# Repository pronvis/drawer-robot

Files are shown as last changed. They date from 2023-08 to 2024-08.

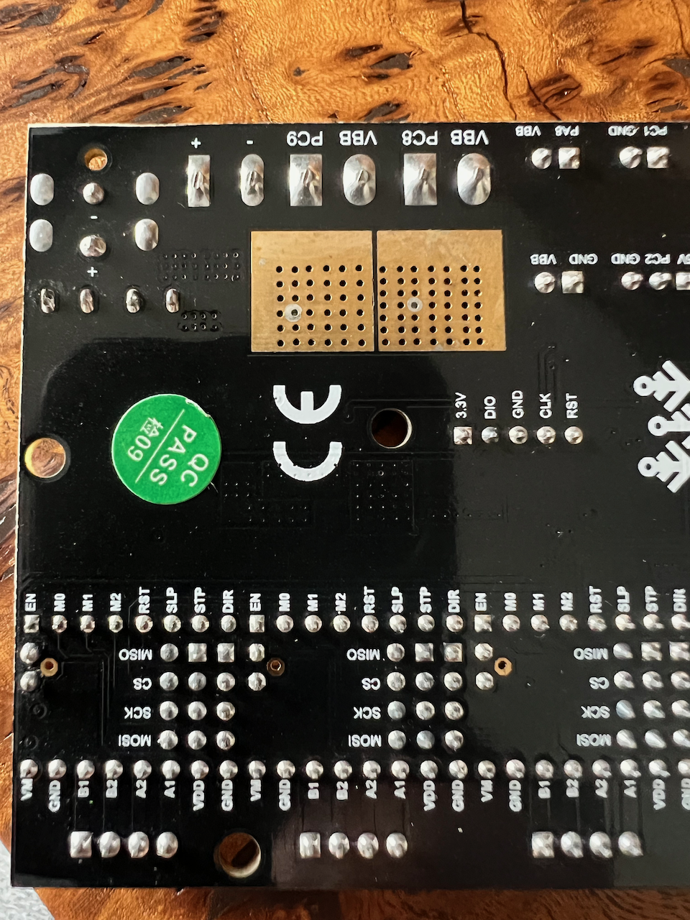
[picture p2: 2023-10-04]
documentation/SKR E3-DIP-V1.1_pins_1.png

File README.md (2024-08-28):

Based on https://github.com/knurling-rs/app-template

## Run
To execute binary file: `cargo xtask run -p {project_name} -b {bin_file_name}`, for example: `cargo xtask run -p experiments -b stepper_configurator`.
Or just `cargo xtask run -b stepper_configurator`, cause `experiments` is the default project for `run` task: `XTASK_RUN_DEFAULT = "experiments"`
To execute main file: `cargo xtask run -p {project_name}`.
To set logging level change env vat `DEFMT_LOG` at `.cargo/config.toml`

### To stop microcontoller
Erase program: `probe-rs erase --chip STM32F103RE`

## Size
To get info about sections size on microcontoller: `cargo xtask size -p {project_name} -b {bin_file_name}`, for example: `cargo xtask size -p experiments -b stepper_configurator`.

## ReadObj
To get info about binary object: `cargo xtask readobj -p {project_name} -b {bin_file_name}`, for example: `cargo xtask readobj -p experiments -b stepper_configurator`.

## Attach
To attach to running microcontroller, example:
1) `probe-rs attach $CARGO_TARGET_DIR/thumbv7m-none-eabi/release/companion --chip STM32F103C8 --probe 0483:3748:C296C294070132124647524B4E --log-format "[{t}][{L}] {s}"`
2) `probe-rs attach $CARGO_TARGET_DIR/thumbv7m-none-eabi/release/motherboard --chip STM32F103RE --probe 0483:3748:15 --log-format "[{t}][{L}] {s}"`

## TMC2209

Good Vref calculator: https://wiki.fysetc.com/TMC2208/#motor-current-setting
For my steppers (1.7A for phase) Vref should be `1.6970562748477143`,
but I set it to 1.9, cause my friend told me that active cooling required above Vref=1.4

## PS3 controller bluetooth connection

To connect PS3 controller to HC-05 you need to set master address. To do that:
- install SixAxisPairTool (for mac get it from [here](https://github.com/user-none/sixaxispairer))
- connect PS3 to PC
- set master address

## Debugging

1. run `openopcd` in one terminal
2. run `arm-none-eabi-gdb -x openocd.gdb -q {path_to_bin_file}` or change `runner` at `crate/{project}/.cargo/config.toml`
For example: `arm-none-eabi-gdb -x openocd.gdb -q ~/rust/rust_build_artifacts/thumbv7m-none-eabi/release/minimal_x`

## Manual Flashing

1. Build ELF file (`cargo build`)
2. `arm-none-eabi-objcopy -O binary $CARGO_TARGET_DIR/thumbv7m-none-eabi/release/{binary_name} {path_to_output}.bin`
3. `st-flash write {path_to_output}.bin 0x08000000`

## HC-05

Use arduino device to configure HC-05. Scetch and connection image is in folder `./hc05_arduino_configurator/`.
With pressed button `reset` connect HC-05 to arduino - diod whould blink once per 2 seconds.

Commands can be found in `./documentation/HC-05_AT_Command_Set.pdf`

One device should be Master. Another one slave.

I set speed to 460800: `AT+UART=460800,0,0`

For slave: 
- `AT+NAME=DrawingRobot_slave`
- `AT+UART=460800,0,0`
- `AT+CMODE=1`
- `AT+ROLE=0`
- get addr, we will need it for master: `AT+ADDR?`

For master: 
- `AT+NAME=DrawingRobot_master`
- `AT+UART=460800,0,0`
- `AT+CMODE=0`
- `AT+BIND={slave_addr}` // replace `:` with `,` in addr string
- `AT+ROLE=1`

For `AT+BIND={slave_addr}` it may require adding zeroes in front each part. For example: `AT+ADDR?` return
`21:13:12622`. To bind that address send this command: `AT+BIND=0021,13,012622`

## Images

Motherboard:


Companion:


companion

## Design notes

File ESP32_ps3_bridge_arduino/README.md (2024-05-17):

## Run
To install firmware you need:
- Arduino IDE
- `PS3 Controller Host` library installed, version 1.1.0
- choose `ESP32-WROOM-DA Module` as a board

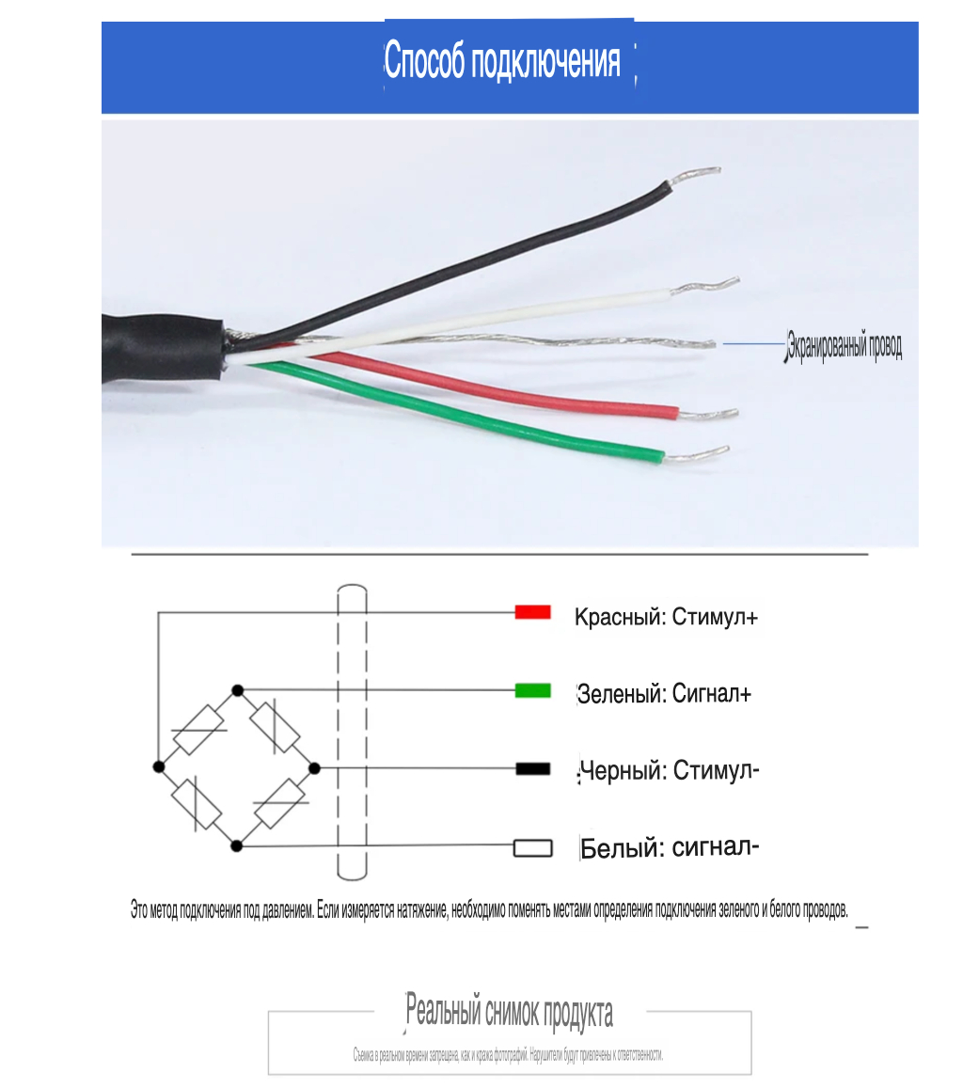
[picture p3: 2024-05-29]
documentation/dymh-106/connection_to_translate.translated.jpg

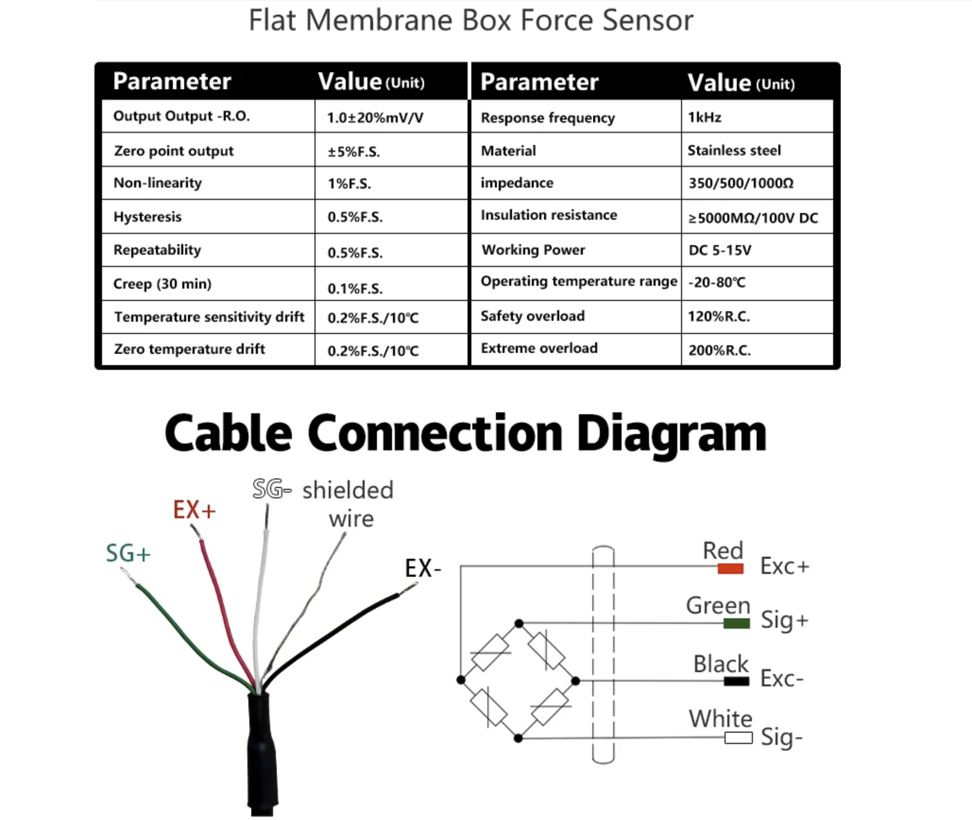
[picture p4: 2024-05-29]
documentation/dymh-106/connection_diagram.png

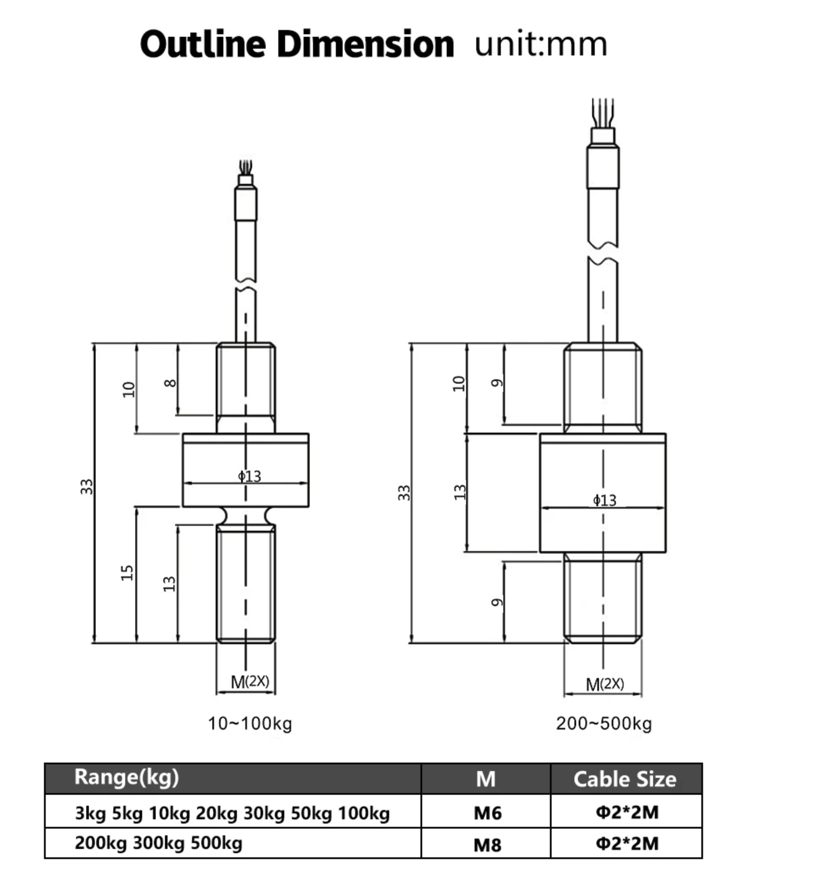
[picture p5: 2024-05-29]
documentation/dymh-106/size.png

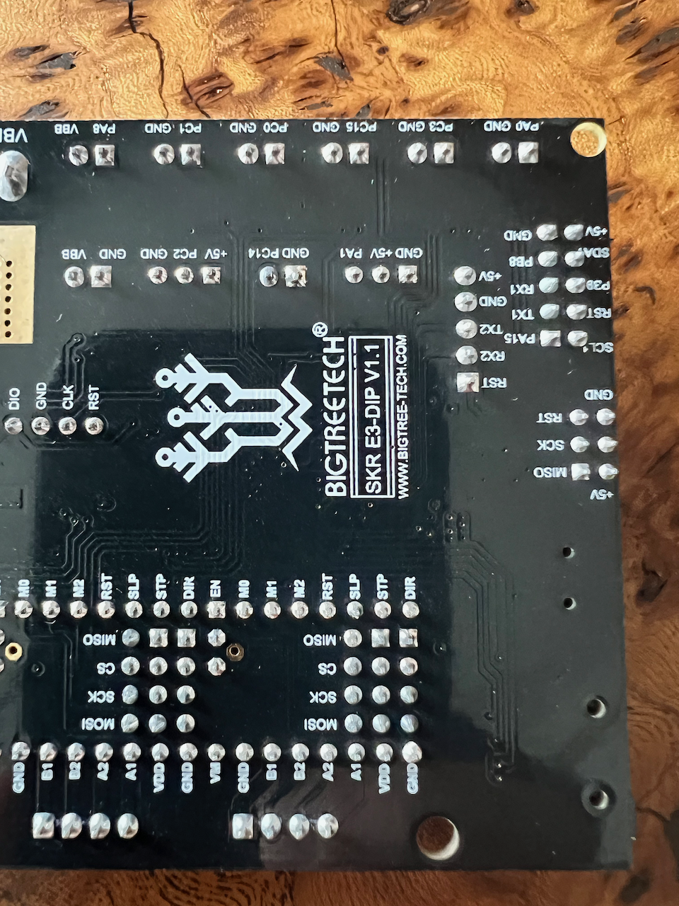
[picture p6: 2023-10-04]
documentation/SKR E3-DIP-V1.1_pins_0.png

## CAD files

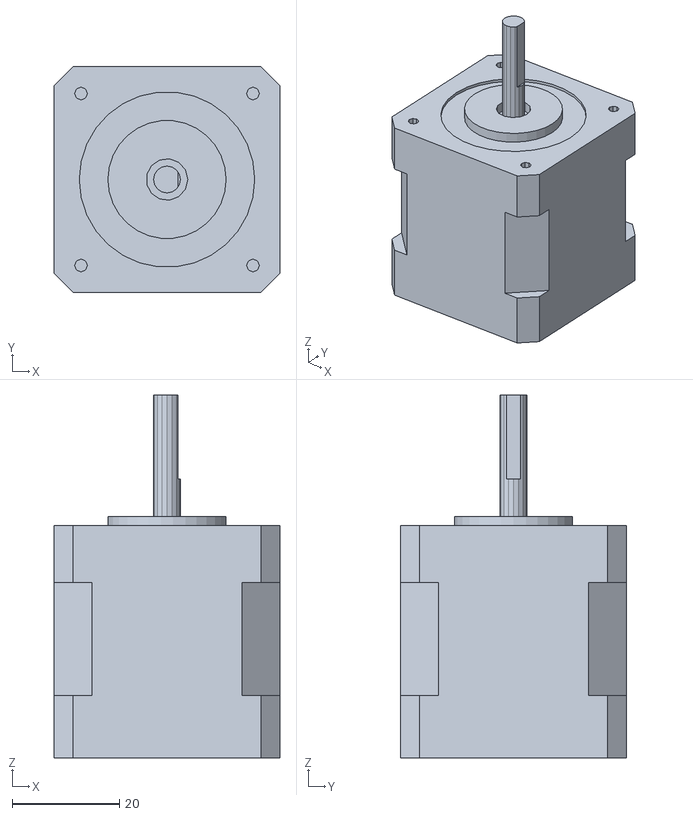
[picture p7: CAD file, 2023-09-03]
open_scad/reduction_gearbox/Nema17.stl
42.0 x 42.0 x 67.5

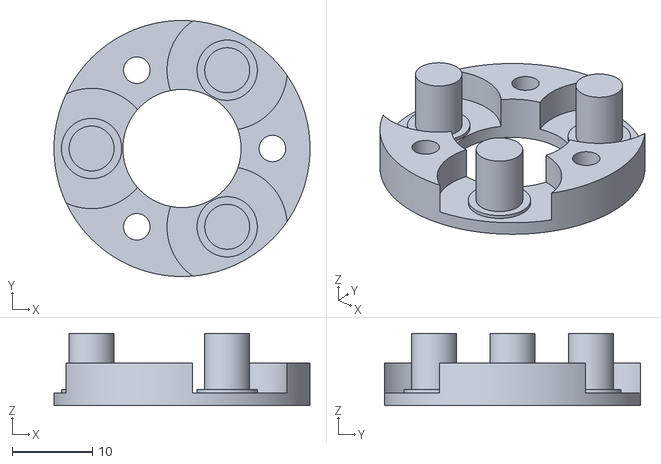
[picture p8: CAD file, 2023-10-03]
open_scad/stl_files/gearbox_carrier_bottom.stl
31.9 x 31.9 x 9.00

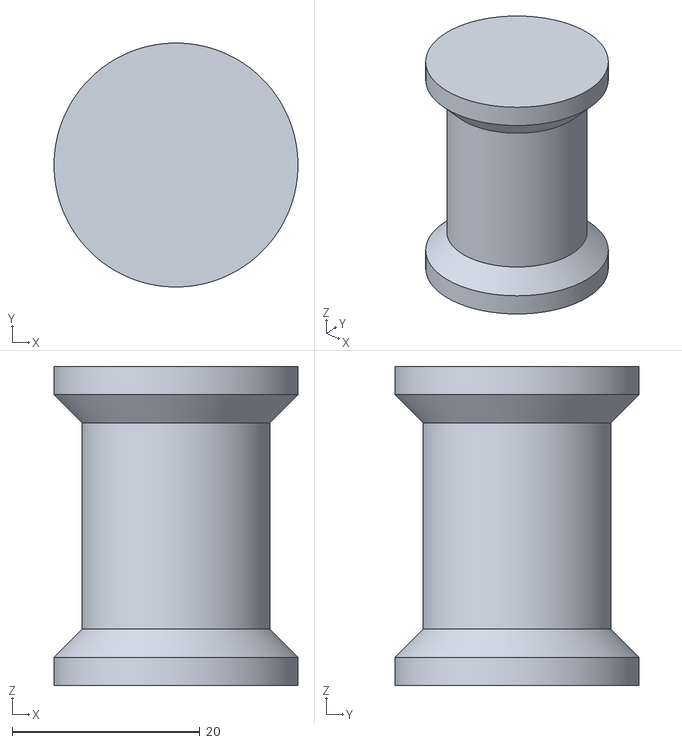
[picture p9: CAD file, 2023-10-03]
open_scad/stl_files/katushka.stl
26.0 x 26.0 x 34.0

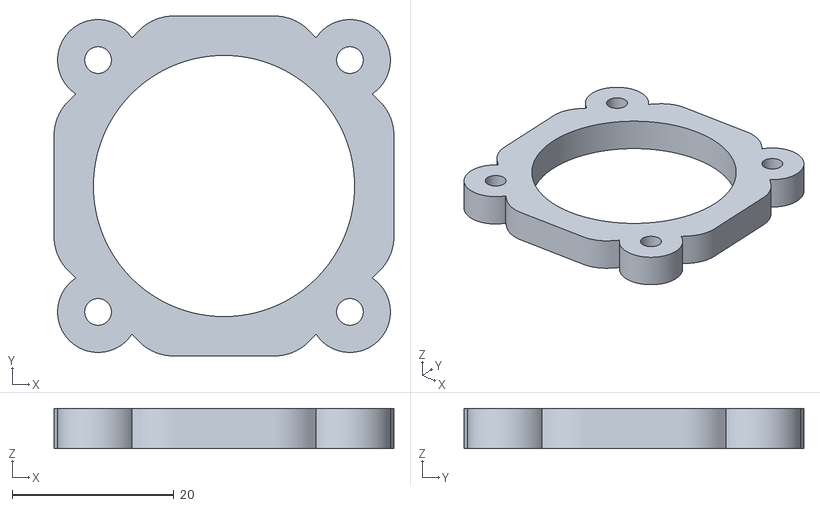
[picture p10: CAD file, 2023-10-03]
open_scad/stl_files/gearbox_fixer.stl
42.0 x 42.0 x 5.00

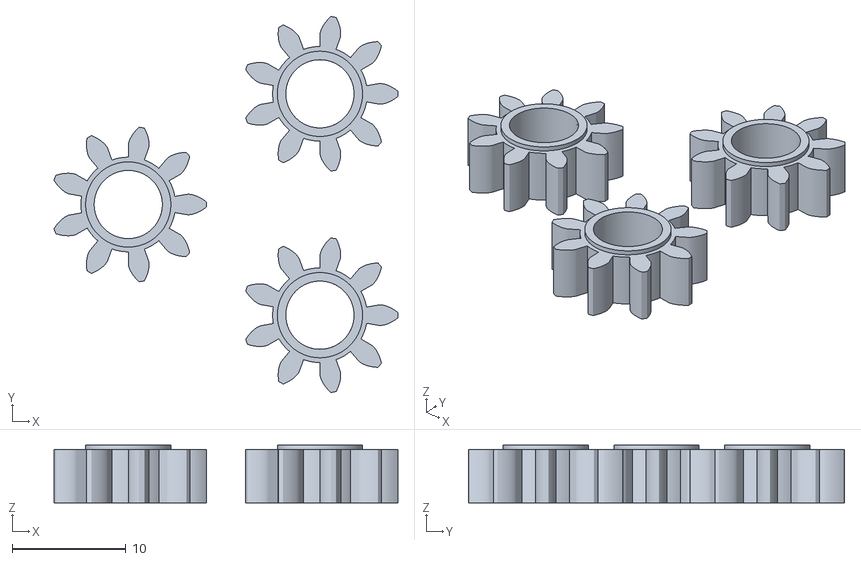
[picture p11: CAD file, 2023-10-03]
open_scad/stl_files/gearbox_planets.stl
30.3 x 33.1 x 5.10

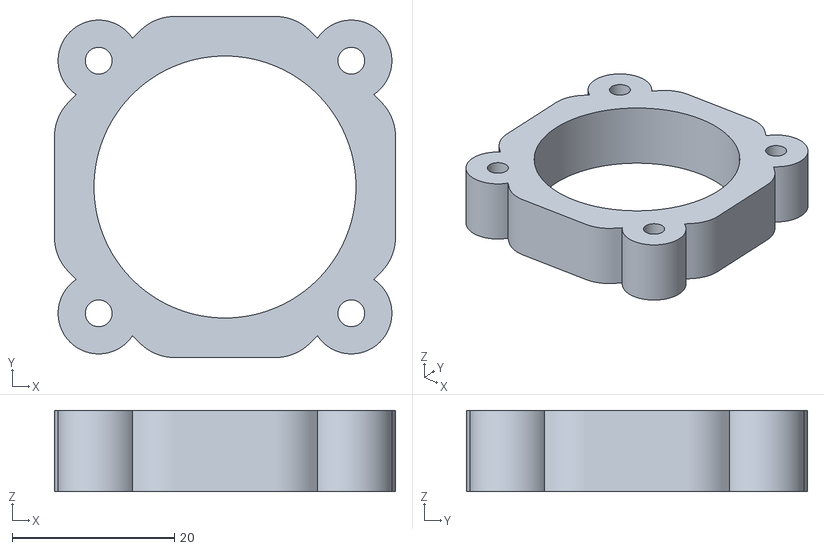
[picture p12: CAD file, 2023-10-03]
open_scad/stl_files/gearbox_motor_mount.stl
42.0 x 42.0 x 10.0

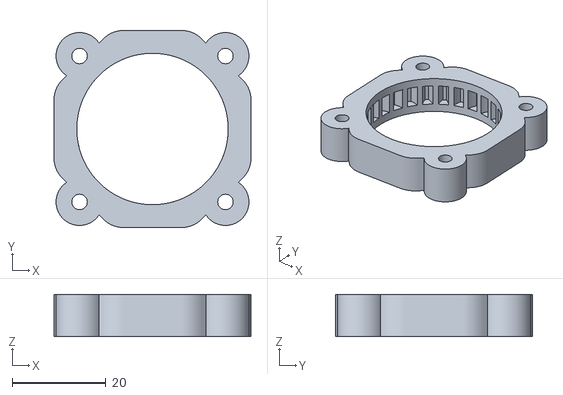
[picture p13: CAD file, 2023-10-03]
open_scad/stl_files/gearbox_ring_gear.stl
42.0 x 42.0 x 9.00

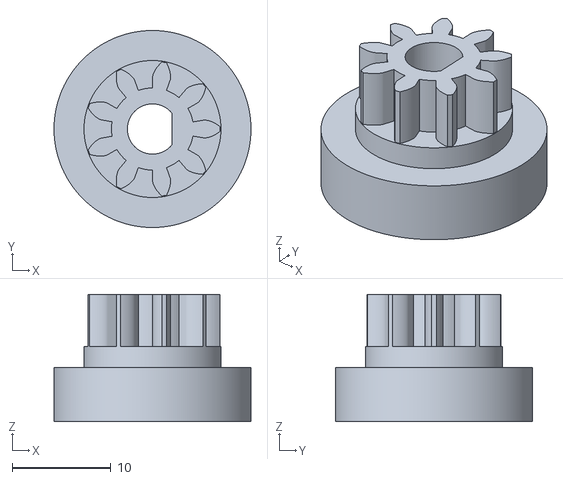
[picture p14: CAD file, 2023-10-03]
open_scad/stl_files/gearbox_motor_gear.stl
20.0 x 20.0 x 12.9

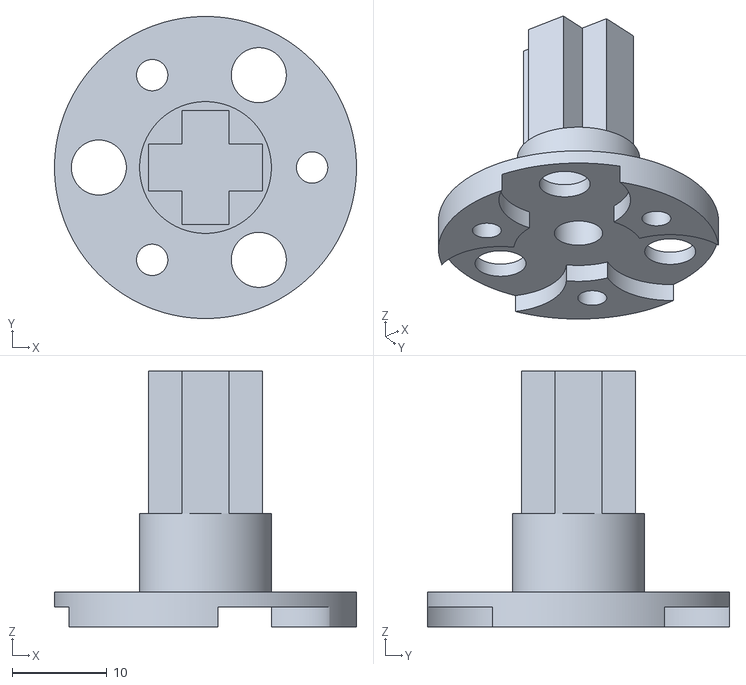
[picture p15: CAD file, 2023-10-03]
open_scad/stl_files/gearbox_carrier_top.stl
31.9 x 31.9 x 27.0

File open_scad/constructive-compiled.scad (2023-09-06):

//BASICFUNCS.SCAD
//This is a part of:
//CONSTRUCTIVE LIBRARY by PPROJ (version from 05.06.2021)
//released under General Public License version 2.

//you only need a single file: constructive-compiled.scad which
//contains all the partial files you find. you can ignore everything else..
//just include it in your code by:
//include <constructive-compiled.scad>

//if you wish to improve the library or make changes to it,
// it might be handier to use:
//include <constructive-all.scad> instead. so you do not have to recreate constructive-compiled.scad from the parts
//every time you make a change to a part of the library

function toInt(str) = 
      str=="-"?undef
      :str[0]=="-"? -1*toInt([for(i=[1:1:len(str)-1])str[i]])
    :let(d = [for (s = str) ord(s) - 48], l = len(d))
[for (i = 0, a = d[i]; i < l; i = i + 1 ,a = i<l?( 10 * a + d[i]):a) a][l-1];

function toIntList(str) =
      let(inList=split(split(str,"[")[1],"]")[0]) len(inList)<1?[]:[for(s=split(inList,","))toInt(s)];

function join( arr, sp="", _ret="", _i=0)=
   (
    _i<len(arr)?
        join( arr, sp=sp
            , _ret= str(_ret,_i==0?"":sp,arr[_i])
            , _i=_i+1 )
    :_ret
   );

function checkInside(blockOpeners,chr) =
                    ( len (blockOpeners) > 0
                      && blockOpeners[0] == "[" && chr == "]")
                   || (len(blockOpeners) > 0
                      && blockOpeners[0] == "(" && chr == ")") ? [for(i=[1:1:len(blockOpeners)-1])blockOpeners[i]]
                                              :  chr=="(" || chr=="[" ? concat([chr],blockOpeners)
                                              :  blockOpeners;

//------
function split(str, sep=" ", i=0, word="", v=[], blockOpeners=[]) =
  str ==undef ? undef
	: i == len(str) ? concat(v, word)
  : (len(blockOpeners)>0 || (str[i] != sep)) ? split(str, sep, i+1, str(word, str[i]), v
      , checkInside(blockOpeners,str[i]))
	: split(str, sep, i+1, "", concat(v, word),checkInside(blockOpeners,str[i])) ;

function splitSimple(str, sep=" ", i=0, word="", v=[]) =
  str ==undef ? undef :
	i == len(str) ? concat(v, word) :
	str[i] == sep ? split(str, sep, i+1, "", concat(v, word)) :
	split(str, sep, i+1, str(word, str[i]), v);



// some general utility functions
function debugprint(s) = search(s, []) || true;

function multV(what,byWhat=[1]) = [for (i = [ 0 : min(len(what),len(byWhat)) - 1 ]) what[i]*byWhat[i]];
function absV(vector) = [for (i = [ 0 : len(vector) - 1 ]) abs(vector[i])];
function addToV(vector,scalar=0) = [for (i = [ 0 : len(vector) - 1 ]) vector[i]+scalar];
function zeroIfUndef(what) = (what==undef)?0:what;
function falseIfUndef(what) = (what==undef)?false:what;

function zeroIfNot(boolVal)= (boolVal)?1:0;
function zeroIf(boolVal)= (boolVal)?0:1;


//returns the maximum elemnt of the i's component of a vector of vectors
// for example of a[1][3], a[2][3], a[3][3], a[4][3]
// the i parametere is only needed internally and can be ommitedin calls
// like: maximum(a,3);
function maximum(a,componentIndex, i = 0) = (i < len(a) - 1)
        ? max(a[i][componentIndex], maximum(a,componentIndex, i +1)) : a[i][componentIndex];
//just like mximum above but the minimum
function minimum(a,componentIndex, i = 0) = (i < len(a) - 1)
        ? min(a[i][componentIndex], minimum(a,componentIndex, i +1)) : a[i][componentIndex];

//adds an element to a vector
function push(vector,element)=concat(vector,[element]);
//gets last element from a vetor
function top(vector)=vector[len(vector)-1];

function ifAnyOf(where,what,sep=":")= (len([for(el=split(where,sep))
                if(str(what)==el)1])!=0)?true:false;
function anyPairMatches(setA,setB)=
      len([for(a=setA,b=setB)if(str(a)==str(b))1])!=0;

function encloses(where,what) =
      (len([for(el=split(where,","))
          if(str(what)==el)1])!=0)?true:false;
function enclosesOneOf(where,commaSeparatedListOfWhat) =
    (len([for(el=split(commaSeparatedListOfWhat,","))
            if(encloses(where,el))1])!=0)?true:false;


//---------------------------------------------------
// List helpers

/*!
  Creates a list from a range:
  range([0:2:6]) => [0,2,4,6]
*/
function range(r) = [ for(x=r) x ];

/*!
  Reverses a list:
  reverse([1,2,3]) => [3,2,1]
*/
function reverse(list) = [for (i = [len(list)-1:-1:0]) list[i]];

/*!
  Extracts a subarray from index begin (inclusive) to end (exclusive)
  FIXME: Change name to use list instead of array?
  subarray([1,2,3,4], 1, 2) => [2,3]
*/
function subarray(list,begin=0,end=-1) = [
    let(end = end < 0 ? len(list) : end)
      for (i = [begin : 1 : end-1])
        list[i]
];

/*!
  Returns a copy of a list with the element at index i set to x
  set([1,2,3,4], 2, 5) => [1,2,5,4]
*/
function set(list, i, x) = [for (i_=[0:len(list)-1]) i == i_ ? x : list[i_]];

/*!
  Remove element from the list by index.
  remove([4,3,2,1],1) => [4,2,1]
*/
function remove(list, i) = [for (i_=[0:1:len(list)-2]) list[i_ < i ? i_ : i_ + 1]];


/*!
  Flattens a list one level:
  flatten([[0,1],[2,3]]) => [0,1,2,3]
*/
function flatten(list) = [ for (i = list, v = i) v ];

//function flatten(vec,max=inf) = [let(i=min(len(vec)-1,max)) concat(flatten(vec,i-1),vec[i])];
function splitBodies(bodyListCommaSeparated)= flatten(concat(
    [for( body=split(bodyListCommaSeparated,","))
              if(len(body)>0) [for(i=[0:1: len(split(body,"."))-1])
                            let(substep = split(body,".")[i])(i==0 //&& len(split(body,"."))>2
                              ?substep:
                            str(split(body,".")[0],".",substep))]])) ;
//str(split(body,".")[0],".",substep)]

function mapByStringKey(stringKey,objArray) = [for(i=[0:1:len(objArray)]) if(objArray[i][0] == stringKey)objArray[i]];
//function find(stringKey,arrayVect)occurencesAt(stringKey,arrayVect)

function vals(val1,val2,val3,val4,val5
			,val6,val7,val8,val9,val10)
		= ( val2==undef)
		?val1[$valPtr]
		:concat([val1],[val2]
			,[val3]
			,[val4]
			,[val5]
			,[val6]
			,[val7]
			,[val8]
			,[val9]
			,[val10])[$valPtr];

function valsFromList(list=[undef])=list[$valPtr];

function collect(val1,val2,val3,val4,val5
			,val6,val7,val8,val9,val10) =
		[for(a=concat([val1]
			,[val2]
			,[val3]
			,[val4]
			,[val5]
			,[val6]
			,[val7]
			,[val8]
			,[val9]
			,[val10])) if(a!=undef)a];
//GLOBALS.SCAD
//This is a part of:
//CONSTRUCTIVE LIBRARY by PPROJ (version from 05.06.2021)
//released under General Public License version 2.

//you only need a single file: constructive-compiled.scad which
//contains all the partial files you find. you can ignore everything else..
//just include it in your code by:
//include <constructive-compiled.scad>

//if you wish to improve the library or make changes to it,
// it might be handier to use:
//include <constructive-all.scad> instead. so you do not have to recreate constructive-compiled.scad from the parts
//every time you make a change to a part of the library



$padding=.8;
$margin=.8;


$sideX=undef;
$sideY=undef;
$sideZ=undef;


$derivedParts=[];

$autoColor=[undef,1];

UNITY=        [ [1, 0, 0, 0],
      					[0, 1, 0, 0],
       					[0, 0, 1, 0],
       					[0, 0, 0, 1]];
$placement =UNITY;
infinity=1e308;
inf=infinity;


$placementStack=[["origin",UNITY]];
$placementStackTop=0;

$summingUp=false;

$hulling=false;
$removing=false;
$removingAgain=false;
$addingAgain=false;
$partOfAddAfterRemoving=false;
$inverted=false;
$beforeRemoving=true;
$enclosing=false;
$currentBody=undef;

$valPtr=0;

$arc=undef;
$x=undef;
$y=undef;
$h=undef;
$d=undef;
$d2=undef;
$dInner=undef;
$dOuter=undef;
$wall=0;
$solid=false;
$hBore=undef;


//used to track transformations made by move() to be still
// able to use  connect()
$centerLineStack=[[0,0,0,"m"]];



//global constants which an be used with the align() function
//like align(TORIGHT,TOUP) box(side=10);
// instead of toRight() toUp() box(side=10);
RESET=[0,0,0,1,1,1];
NOCHANGE=[0,0,0,0,0,0];

XCENTER=[0,0,0,1,0,0];
YCENTER=[0,0,0,0,1,0];
ZCENTER=[0,0,0,0,0,1];

TORIGHT=[1,0,0,1,0,0];
TOREAR=  [0,1,0,0,1,0];
TOBEHIND=[0,1,0,0,1,0];

TOUP=[0,0,1,0,0,1];
TODOWN=-1* TOUP;
TOLEFT=-1* TORIGHT;
TOFRONT=-1* TOBEHIND;


/***internal global variables end************************/

// TYPEINFO.SCAD
//This is a part of:
//CONSTRUCTIVE LIBRARY by PPROJ (version from 05.06.2021)
//released under General Public License version 2.

//you only need a single file: constructive-compiled.scad which
//contains all the partial files you find. you can ignore everything else..
//just include it in your code by:
//include <constructive-compiled.scad>

//if you wish to improve the library or make changes to it,
// it might be handier to use:
//include <constructive-all.scad> instead. so you do not have to recreate constructive-compiled.scad from the parts
//every time you make a change to a part of the library
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

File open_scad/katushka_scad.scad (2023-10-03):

$fn= $preview ? 32 : 300;

total_height = 34;

base_height = 6;

center_height = total_height - base_height*2;
center_radius = 10;

base_radius = center_radius + 3;

base_shift = center_height / 2 + base_height/4;

module hole() {
    difference() {
        cylinder(total_height, 2.5, 2.5, center=true);
        translate([4, 0, 0]) {
            cube([4, 4, total_height], center=true);
        }   
    }
}

module center() {
        cylinder(center_height, center_radius, center_radius, center = true);
}

module base() {
        union() {        
            cylinder(base_height/2, base_radius, center_radius, center = true);
            translate([0, 0, -base_height/2]) {
                cylinder(base_height/2, base_radius, base_radius, center = true);
            }
        }
}

difference() {
    union() {
        center();

        translate([0, 0, -base_shift]) {
            base();
        }

        translate([0, 0, base_shift]) {
            rotate([180,0,0]) { 
                base();
            }
        }
    }

    cube_height = 15 + 1.6;
    margin = 0.25;
    translate([0,0, -base_shift - base_height/2 -1.6 + cube_height/2]) {
        cube([5 + margin, 12 + margin, cube_height], center = true);
    }

    mirror([1,1,0])
    translate([0,0, -base_shift - base_height/2 -1.6 + cube_height/2]) {
        cube([5 + margin, 12 + margin, cube_height], center = true);
    }

}

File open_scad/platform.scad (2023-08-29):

include <constructive-compiled.scad>
$skinThick=5;

full_size = [100, 50, 50];
dymh_diameter = 6;
dymh_big_diameter = 14;
wall_width = 5;

partColors = [
    ["base", yellow, 0.8],
    ["screws",grey,0.8],
    ["screwMounts",red,.8],
    ["stm32",green,.8],
    ["top",blue,.8]
];

assemble("base,stm32,top,screws,screwMounts,stm32_protection") {
    base();
    top();
}


module base() autoColor(custom=partColors)
{
    add("base") chamfer(0, 0, -dymh_big_diameter, fnCorner=2) box(x = full_size[0], y = full_size[1], z = full_size[2]);
    remove("base") chamfer(0, 0, -dymh_big_diameter, fnCorner=2) box(x = full_size[0] - wall_width, y = full_size[1] - wall_width, z = full_size[2] - wall_width);
    remove("base") two() reflectY(sides()) two() reflectX(sides()) g(X(-full_size[0]/2), Y(-full_size[1]/2), turnXZ(90), turnYZ(45)) tube(d=dymh_diameter,h=40, solid=true);

    two() reflectY(sides()) two() reflectX(sides()) g(X(-full_size[0]/3 + 10), Y(-full_size[1]/2 + wall_width + 2), Z(-full_size[2]/4)) {
        hull() add("screwMounts") tube(d=8, h=full_size[2]/2, solid=true) Y(-wall_width/2) box(8, z=full_size[2]/2);
        remove("screwMounts,base") Z(-full_size[2]/4 + 5) screwM4(h=full_size[2]/2, noNut=true);
    }

    remove("base") align(TOUP) box(x = full_size[0]+10, y = full_size[1]+10, z = full_size[2]);
}

module top() autoColor(custom=partColors)
{
    g(Z(full_size[2])) {
        add("top") chamfer(0, 0, -dymh_big_diameter, fnCorner=2) box(x = full_size[0], y = full_size[1], z = full_size[2] / 4);
        add("stm32_protection") pieces(2) g(X(-full_size[0]/2 + full_size[0]/4 + 10), X(span(full_size[0]/2 - 20)), turnYZ(90)) tube(d=4, h=full_size[1], solid=true);
        remove("top") chamfer(0, 0, -dymh_big_diameter, fnCorner=2) box(x = full_size[0] - wall_width, y = full_size[1] - wall_width, z = full_size[2] / 2 + wall_width);
        remove("top") two() reflectY(sides()) two() reflectX(sides()) g(X(-full_size[0]/2), Y(-full_size[1]/2), Z(-full_size[2]/8), turnXZ(90), turnYZ(45)) tube(d=dymh_diameter,h=40, solid=true);

        mount_height = 3;
        two() reflectY(sides()) two() reflectX(sides()) g(X(-full_size[0]/3 + 10), Y(-full_size[1]/2 + wall_width + 2), Z(-full_size[2]/8 + mount_height/2)) {
            hull() add("screwMounts") tube(d=8, h=mount_height, solid=true) Y(-wall_width/2) box(8, h=mount_height);
            remove("screwMounts,top") Z(-mount_height) screwM4(h=full_size[2]/4, noNut=true);
        }
    }
}

between_pins = 2.54;
stm32_size = [53, 23, 25];
module stm32_volume() {
    difference() {
        cube(stm32_size); // размер который занимает stm32 
        for (pin = [0 : 19]) {
            translate([1.85 + between_pins * pin, 3, 0]) {
                cube([1, 1, stm32_size[2]]);
            }
        }

        for (pin = [0 : 19]) {
            translate([1.85 + between_pins * pin, stm32_size[1] - 3, 0]) {
                cube([1, 1, stm32_size[2]]);
            }
        }
    }
}
// stm32_volume();


// DYMH-106 size
// {
//     8 - height
//     13 diameter 
// }
function bottom_corners(sizes) = [[0, 0 ,0], [sizes[0], 0, 0], [sizes[0], sizes[1], 0], [0, sizes[1], 0]];

module triangle(katet_size) {
    CubePoints = [
        [  0,  0,  0 ],  //0
        [ katet_size,  0,  0 ],  //1
        [  0,  katet_size,  0 ],  //2
        [  0,  0,  full_size[2] ],  //3
        [ katet_size,  0,  full_size[2] ],  //4
        [  0,  katet_size,  full_size[2] ] //5
    ];

    CubeFaces = [
        [0,1,2],  // bottom
        [3,4,1,0],  // front
        [5,4,3],  // top
        [4,5,2,1],  // back
        [5,3,0,2]
    ]; // left

    polyhedron( CubePoints, CubeFaces );
}

module platform() {
    difference() {
        cube(full_size);
        corners = bottom_corners(full_size);

        for (i = [0:3]) {
            translate( [corners[i][0], corners[i][1], 0] ) {
                rotate([0, 0, 90 * i]) {
                    triangle(10); // for katet=10 gipotenuza will be ~14, which is close to DYMH-106 diameter (biggest part)
                }
            }
        }
    }
}
module inside_platform() {
    local_cube = [for (x = full_size) x - wall_width * 2];
    triangle_katet = 10;
    translate([wall_width, wall_width, wall_width]) {
        difference() {
            cube(local_cube);

            corners = bottom_corners(local_cube);
            for (i = [0:3]) {
                translate([corners[i][0], corners[i][1], 0]) {
                    rotate([0, 0, 90 * i]) {
                        triangle(triangle_katet);
                    }
                }
            }
        }
    }
} 

module plain_drawing() {
    difference() {
        platform();
        inside_platform();
        dymh_holes();
        translate([-10, -10, full_size[2] / 2]) {
            cube([500, 500, 200]);
        }
    }
}

module dymh_holes() {
    corners = bottom_corners(full_size);
    for (i = [0:3]) {
        translate([corners[i][0], corners[i][1], 0]) {
            translate([0, 0, full_size[2] / 2]) {
                rotate([90, 0 , 135 + 90 * i]) {
                    cylinder(20, d1 = dymh_diameter , d2 = dymh_diameter);
                }
            }
        }
    }
}
// plain_drawing();
// module pit_posts() {
//     cylinder()
// }

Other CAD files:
open_scad/reduction_gearbox/planetary_gearbox.scad
open_scad/reduction_gearbox/gears.scad

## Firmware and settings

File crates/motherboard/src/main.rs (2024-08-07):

#![no_main]
#![no_std]
#![feature(type_alias_impl_trait)]
#![feature(slice_as_chunks)]

#[rtic::app(
    device = stm32f1xx_hal::pac,
    peripherals = true,
    // You can usually find the names of the interrupt vectors in the some_hal::pac::interrupt enum.
    dispatchers = [EXTI0, EXTI1, EXTI2, EXTI3, EXTI4]
)]
mod app {

    use defmt_brtt as _; // global logger
    use heapless::pool::singleton::{Box, Pool};
    use robot::Robot;
    use robot_core::display::OledDisplay;
    use robot_core::my_tmc2209::{
        communicator::TMC2209SerialCommunicator, configurator::TMC2209Configurator, Tmc2209Constructor, Tmc2209RequestCh,
        Tmc2209ResponseCh, TMC2209COMMUNICATOR_CLOCK_FREQ,
    };
    use robot_core::robot::{TensionData, TENSION_DATA_CHANNEL_CAPACITY};
    use robot_core::DisplayMemoryPool;
    use robot_core::*;
    use rtic_monotonics::systick::*;
    use rtic_sync::{channel::*, make_channel};
    use stm32f1xx_hal::{
        prelude::*,
        serial::{Config, Serial},
        timer::{Counter, Event},
    };

    const TIMER_CLOCK_FREQ: u32 = 72_000_000;
    static mut DISPLAY_MEMORY_POOL_MEMORY: [u8; 96] = [32u8; 96];

    const PS3_CHANNEL_CAPACITY: usize = robot_core::ps3::CHANNEL_CAPACITY;
    const DISPLAY_CHANNEL_CAPACITY: usize = robot_core::display::CHANNEL_CAPACITY;

    #[shared]
    struct Shared {}

    #[local]
    struct Local {
        ps3_reader: ps3::Ps3Reader,
        ps3_bytes_sender: Sender<'static, u8, PS3_CHANNEL_CAPACITY>,
        tension_data_sender: Sender<'static, TensionData, TENSION_DATA_CHANNEL_CAPACITY>,
        ps3_rx: stm32f1xx_hal::serial::Rx2,
        hc05_rx: stm32f1xx_hal::serial::Rx1,
        display_receiver: Receiver<'static, Box<DisplayMemoryPool>, DISPLAY_CHANNEL_CAPACITY>,
        display_sender: Sender<'static, Box<DisplayMemoryPool>, DISPLAY_CHANNEL_CAPACITY>,
        display: OledDisplay,

        //TMC2209 related
        configurator_0: TMC2209Configurator,
        tmc2209_communicator_timer_0: Counter<stm32f1xx_hal::pac::TIM2, TMC2209COMMUNICATOR_CLOCK_FREQ>,
        communicator_0: TMC2209SerialCommunicator<'C', 10>,

        configurator_1: TMC2209Configurator,
        tmc2209_communicator_timer_1: Counter<stm32f1xx_hal::pac::TIM3, TMC2209COMMUNICATOR_CLOCK_FREQ>,
        communicator_1: TMC2209SerialCommunicator<'C', 11>,

        tmc2209_communicator_timer_2: Counter<stm32f1xx_hal::pac::TIM4, TMC2209COMMUNICATOR_CLOCK_FREQ>,
        configurator_2: TMC2209Configurator,
        communicator_2: TMC2209SerialCommunicator<'C', 12>,

        tmc2209_communicator_timer_3: Counter<stm32f1xx_hal::pac::TIM5, TMC2209COMMUNICATOR_CLOCK_FREQ>,
        configurator_3: TMC2209Configurator,
        communicator_3: TMC2209SerialCommunicator<'D', 2>,
        robot: Robot,
    }

    #[init(local = [
           tmc2209_req_ch_0: Tmc2209RequestCh = Channel::new(),
           tmc2209_rsp_ch_0: Tmc2209ResponseCh = Channel::new(),

           tmc2209_req_ch_1: Tmc2209RequestCh = Channel::new(),
           tmc2209_rsp_ch_1: Tmc2209ResponseCh = Channel::new(),

           tmc2209_req_ch_2: Tmc2209RequestCh = Channel::new(),
           tmc2209_rsp_ch_2: Tmc2209ResponseCh = Channel::new(),

           tmc2209_req_ch_3: Tmc2209RequestCh = Channel::new(),
           tmc2209_rsp_ch_3: Tmc2209ResponseCh = Channel::new(),
    ])]
    fn init(cx: init::Context) -> (Shared, Local) {
        defmt::info!("init");
        unsafe {
            DisplayMemoryPool::grow(&mut DISPLAY_MEMORY_POOL_MEMORY);
        }

        // Take ownership over the raw flash and rcc devices and convert them into the corresponding
        // HAL structs
        let mut flash: stm32f1xx_hal::flash::Parts = cx.device.FLASH.constrain();
        let rcc: stm32f1xx_hal::rcc::Rcc = cx.device.RCC.constrain();

        // Freeze the configuration of all the clocks in the system and store the frozen frequencies in
        // `clocks`
        // with those values one second equals 'delay_cycles: u32 = 72_000_000'
        let clocks = rcc
            .cfgr
            .use_hse(8.MHz())
            .sysclk(TIMER_CLOCK_FREQ.Hz())
            .pclk1(36.MHz())
            .pclk2(TIMER_CLOCK_FREQ.Hz())
            .freeze(&mut flash.acr);

        if !clocks.usbclk_valid() {
            panic!("Clock parameter values are wrong!");
        }

        let mut gpioa: stm32f1xx_hal::gpio::gpioa::Parts = cx.device.GPIOA.split();
        let mut gpiob: stm32f1xx_hal::gpio::gpiob::Parts = cx.device.GPIOB.split();
        let mut gpioc: stm32f1xx_hal::gpio::gpioc::Parts = cx.device.GPIOC.split();
        let mut gpiod: stm32f1xx_hal::gpio::gpiod::Parts = cx.device.GPIOD.split();
        let mut afio = cx.device.AFIO.constrain();

        // STEPPER 0
        let en = gpioc.pc7.into_push_pull_output(&mut gpioc.crl);
        let x_stepper_uart_pin = gpioc.pc10.into_dynamic(&mut gpioc.crh);
        let tmc2209_0 = Tmc2209Constructor::new(
            en,
            x_stepper_uart_pin,
            cx.device.TIM2,
            &clocks,
            cx.local.tmc2209_req_ch_0,
            cx.local.tmc2209_rsp_ch_0,
        );

        // // STEPPER 1
        let en = gpiob.pb14.into_push_pull_output(&mut gpiob.crh);
        let y_stepper_uart_pin = gpioc.pc11.into_dynamic(&mut gpioc.crh);
        let tmc2209_1 = Tmc2209Constructor::new(
            en,
            y_stepper_uart_pin,
            cx.device.TIM3,
            &clocks,
            cx.local.tmc2209_req_ch_1,
            cx.local.tmc2209_rsp_ch_1,
        );

        // // STEPPER 2
        let en = gpiob.pb11.into_push_pull_output(&mut gpiob.crh);
        let z_stepper_uart_pin = gpioc.pc12.into_dynamic(&mut gpioc.crh);
        let tmc2209_2 = Tmc2209Constructor::new(
            en,
            z_stepper_uart_pin,
            cx.device.TIM4,
            &clocks,
            cx.local.tmc2209_req_ch_2,
            cx.local.tmc2209_rsp_ch_2,
        );

        // // STEPPER 3
        let en = gpiob.pb1.into_push_pull_output(&mut gpiob.crl);
        let e_stepper_uart_pin = gpiod.pd2.into_dynamic(&mut gpiod.crl);
        let tmc2209_3 = Tmc2209Constructor::new(
            en,
            e_stepper_uart_pin,
            cx.device.TIM5,
            &clocks,
            cx.local.tmc2209_req_ch_3,
            cx.local.tmc2209_rsp_ch_3,
        );

        // USART1 for HC-05
        let hc05_tx = gpioa.pa9.into_alternate_push_pull(&mut gpioa.crh);
        let hc05_rx = gpioa.pa10.into_pull_up_input(&mut gpioa.crh);

        let mut serial_usart1 = Serial::new(
            cx.device.USART1,
            (hc05_tx, hc05_rx),
            &mut afio.mapr,
            Config::default()
                .baudrate(460800.bps())
                .wordlength_8bits()
                .stopbits(stm32f1xx_hal::serial::StopBits::STOP1)
                .parity_none(),
            &clocks,
        );
        serial_usart1.listen(stm32f1xx_hal::serial::Event::Rxne);
        let (hc05_tx, hc05_rx) = serial_usart1.split();

        // USART2 (esp32)
        let ps3_tx = gpioa.pa2.into_alternate_push_pull(&mut gpioa.crl);
        let ps3_rx = gpioa.pa3.into_pull_up_input(&mut gpioa.crl);
        let mut serial_usart2 = Serial::new(
            cx.device.USART2,
            (ps3_tx, ps3_rx),
            &mut afio.mapr,
            Config::default()
                .baudrate(57600.bps())
                .wordlength_8bits()
                .stopbits(stm32f1xx_hal::serial::StopBits::STOP1)
                .parity_none(),
            &clocks,
        );
        serial_usart2.listen(stm32f1xx_hal::serial::Event::Rxne);
        let (_, ps3_rx) = serial_usart2.split();

        let (ps3_bytes_sender, ps3_bytes_receiver) = make_channel!(u8, PS3_CHANNEL_CAPACITY);
        let (ps3_commands_sender, ps3_commands_receiver) = make_channel!(ps3::Ps3Command, PS3_CHANNEL_CAPACITY);
        let ps3_reader = ps3::Ps3Reader::new(ps3_bytes_receiver, ps3_commands_sender);

        // SSD1306 display pins
        let scl: Scl1Pin = gpiob.pb8.into_alternate_open_drain(&mut gpiob.crh);
        let sda: Sda1Pin = gpiob.pb9.into_alternate_open_drain(&mut gpiob.crh);
        let display = OledDisplay::new(scl, sda, &mut afio, clocks.clone(), cx.device.I2C1);
        let (display_sender, display_receiver) = make_channel!(Box<DisplayMemoryPool>, DISPLAY_CHANNEL_CAPACITY);

        // ROBOT
        let (tension_data_sender, tension_data_receiver) = make_channel!(TensionData, TENSION_DATA_CHANNEL_CAPACITY);
        let robot = Robot::new(
            tmc2209_0.req_sender,
            tmc2209_1.req_sender,
            tmc2209_2.req_sender,
            tmc2209_3.req_sender,
            ps3_commands_receiver,
            tension_data_receiver,
            hc05_tx,
            display_sender.clone(),
        );

        steppers_conf_task::spawn().ok();
        ps3_reader_task::spawn().unwrap();
        robot_task::spawn().unwrap();

        (
            Shared {},
            Local {
                ps3_rx,
                hc05_rx,
                ps3_bytes_sender,
                ps3_reader,
                tension_data_sender,
                display_receiver,
                display_sender,
                display,

                //TMC2209 related
                configurator_3: tmc2209_3.configurator,
                communicator_3: tmc2209_3.communicator,
                tmc2209_communicator_timer_3: tmc2209_3.timer,

                configurator_2: tmc2209_2.configurator,
                communicator_2: tmc2209_2.communicator,
                tmc2209_communicator_timer_2: tmc2209_2.timer,

                configurator_1: tmc2209_1.configurator,
                communicator_1: tmc2209_1.communicator,
                tmc2209_communicator_timer_1: tmc2209_1.timer,

                configurator_0: tmc2209_0.configurator,
                communicator_0: tmc2209_0.communicator,
                tmc2209_communicator_timer_0: tmc2209_0.timer,
                robot,
            },
        )
    }

    #[idle(local = [display_receiver, display])]
    fn idle(cx: idle::Context) -> ! {
        loop {
            if let Ok(message) = cx.local.display_receiver.try_recv() {
                cx.local.display.print(message);
            }
        }
    }

    #[task(priority = 9, local = [ configurator_0, configurator_1, configurator_2, configurator_3 ])]
    async fn steppers_conf_task(cx: steppers_conf_task::Context) {
        debug_configurator_res(0, cx.local.configurator_0.setup().await);
        debug_configurator_res(1, cx.local.configurator_1.setup().await);
        debug_configurator_res(2, cx.local.configurator_2.setup().await);
        debug_configurator_res(3, cx.local.configurator_3.setup().await);
    }

    fn debug_configurator_res(i: u8, result: Result<(), ()>) {
        match result {
            Ok(_) => {
                defmt::debug!("Stepper #{}: driver configured successfully!", i);
            }
            Err(_) => {
                panic!("Stepper #{}: fail to configure driver!", i);
            }
        }
    }

    #[task( priority = 4, local = [  ps3_reader  ])]
    async fn ps3_reader_task(cx: ps3_reader_task::Context) {
        loop {
            cx.local.ps3_reader.work().await;
        }
    }

    #[task( priority = 1, local = [robot])]
    async fn robot_task(cx: robot_task::Context) {
        loop {
            cx.local.robot.work().await;
        }
    }

    #[task(binds = USART1, priority = 15, local = [ tension_data_sender, hc05_rx, data_to_receive: [u8; 16] = [0; 16], counter: usize = 0 ])]
    fn hc05_reader(cx: hc05_reader::Context) {
        let rx = cx.local.hc05_rx;
        let counter = cx.local.counter;
        if rx.is_rx_not_empty() {
            let received = rx.read();
            match received {
                Ok(read) => {
                    if read == robot_core::COMPANION_SYNC {
                        if *counter != 0 {
                            defmt::warn!("receive SYNC byte when counter = {}", *counter);
                        }
                        *counter = 0;
                    } else {
                        cx.local.data_to_receive[*counter] = read;
                        *counter += 1;
                    }

                    if *counter == 16 {
                        *counter = 0;
                        let splitted = cx.local.data_to_receive[0..16].as_chunks::<4>().0;
                        let tension_data = TensionData {
                            t0: i32::from_be_bytes(splitted[0]),
                            t1: i32::from_be_bytes(splitted[1]),
                            t2: i32::from_be_bytes(splitted[2]),
                            t3: i32::from_be_bytes(splitted[3]),
                        };

                        defmt::debug!(
                            "get tension data: {}:{}:{}:{}",
                            tension_data.t0,
                            tension_data.t1,
                            tension_data.t2,
                            tension_data.t3
                        );
                        cx.local.tension_data_sender.try_send(tension_data).err().map(|err| {
                            defmt::error!("fail to send tension_data to tension_data_sender: {:?}", defmt::Debug2Format(&err));
                        });
                    }
                }

                Err(err) => {
                    defmt::error!("read err: {:?}", defmt::Debug2Format(&err));
                    rx.clear_idle_interrupt();
                }
            }
        }
    }

    #[task(binds = USART2, priority = 9, local = [ ps3_rx, ps3_bytes_sender ])]
    fn esp32_reader(cx: esp32_reader::Context) {
        let rx = cx.local.ps3_rx;
        if rx.is_rx_not_empty() {
            let received = rx.read();
            match received {
                Ok(read) => {
                    cx.local.ps3_bytes_sender.try_send(read).err().map(|err| {
                        defmt::debug!("fail to send bytes to ps3_reader: {:?}", defmt::Debug2Format(&err));
                    });
                }

                Err(err) => {
                    defmt::trace!("data from esp32 read err: {:?}", defmt::Debug2Format(&err));
                }
            }
        }
    }

    #[task(binds = TIM2, priority = 10, local = [communicator_0, tmc2209_communicator_timer_0])]
    fn communicator_task_0(cx: communicator_task_0::Context) {
        cx.local.tmc2209_communicator_timer_0.clear_interrupt(Event::Update);
        cx.local.communicator_0.handle_interrupt();
    }

    #[task(binds = TIM3, priority = 10, local = [communicator_1, tmc2209_communicator_timer_1])]
    fn communicator_task_1(cx: communicator_task_1::Context) {
        cx.local.tmc2209_communicator_timer_1.clear_interrupt(Event::Update);
        cx.local.communicator_1.handle_interrupt();
    }

    #[task(binds = TIM4, priority = 10, local = [communicator_2, tmc2209_communicator_timer_2])]
    fn communicator_task_2(cx: communicator_task_2::Context) {
        cx.local.tmc2209_communicator_timer_2.clear_interrupt(Event::Update);
        cx.local.communicator_2.handle_interrupt();
    }

    #[task(binds = TIM5, priority = 10, local = [communicator_3, tmc2209_communicator_timer_3])]
    fn communicator_task_3(cx: communicator_task_3::Context) {
        cx.local.tmc2209_communicator_timer_3.clear_interrupt(Event::Update);
        cx.local.communicator_3.handle_interrupt();
    }
}

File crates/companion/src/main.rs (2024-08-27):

#![no_main]
#![no_std]
#![feature(type_alias_impl_trait)]

use core::fmt::Pointer;

#[rtic::app(
    device = stm32f1xx_hal::pac,
    peripherals = true,
    // You can usually find the names of the interrupt vectors in the some_hal::pac::interrupt enum.
    dispatchers = [EXTI0, EXTI1, EXTI2, EXTI3, EXTI4]
    // dispatchers = [PVD, WWDG, RTC, SPI1]
)]
mod app {
    use ads1256::{Channel, Config as Ads1256Config, SamplingRate, ADS1256, PGA};
    use defmt_brtt as _; // global logger
    use embedded_hal::digital::OutputPin;
    use heapless::spsc::{Consumer, Producer, Queue};
    use robot_core::{robot::TensionData, DEFAULT_DYMH06_VALUE, *};
    use stm32f1xx_hal::{
        gpio::{gpioa, Alternate, Output, Pin, PullUp},
        pac::SPI1,
        prelude::*,
        serial::{Config, Serial},
        spi::{self, Mode, Phase, Polarity, Slave, Spi, Spi1NoRemap},
        timer::{counter, Counter, Delay, Event},
    };

    const MAIN_CLOCK_FREQ: u32 = 72_000_000;
    const READ_TIMER_CLOCK_FREQ: u32 = 10_000;
    const SEND_TIMER_CLOCK_FREQ: u32 = 10_000;
    const ADS1256_TIMER_CLOCK_FREQ: u32 = 2_000_000;

    const DYMH_106_REQ_FREQ: u32 = 500;
    const DYMH_106_QUEUE_SIZE: usize = 30;
    //TODO: 30 times per second... looks like not enough
    const SEND_TIMER_MILLIS_DELAY: u32 = 40;

    //NOTE: To configure dymh106 data sending frequency think about those elements:
    // 1) DYMH_106_RESP_FREQ - freq that you get the data from ads1256 (for all 4 sensors)
    // 2) ads1256 'SamplingRate' - small value gets small noise, but require more time to get data.
    // 3) 'send_timer' delay
    // 4) HC-05 Baud Rate - you cant send data fast with small baud rate
    // 5) DYMH_106_QUEUE_SIZE - queue to buffering DYMH106 data
    // Current values:
    // DYMH_106_REQ_FREQ = 500
    // send_timer.delay = 40 millis
    // DYMH_106_REQ_FREQ / (1.secs() / send_timer.delay) = 20
    // Means averaging on ~20 elements in cache
    // DYMH_106_QUEUE_SIZE = 30
    type Ads1256 = ADS1256<
        Spi<
            stm32f1xx_hal::pac::SPI1,
            Spi1NoRemap,
            (
                stm32f1xx_hal::gpio::Pin<'A', 5, stm32f1xx_hal::gpio::Alternate>,
                stm32f1xx_hal::gpio::Pin<'A', 6>,
                stm32f1xx_hal::gpio::Pin<'A', 7, stm32f1xx_hal::gpio::Alternate>,
            ),
            u8,
        >,
        stm32f1xx_hal::gpio::Pin<'A', 4, stm32f1xx_hal::gpio::Output>,
        stm32f1xx_hal::gpio::Pin<'A', 3, stm32f1xx_hal::gpio::Output>,
        stm32f1xx_hal::gpio::Pin<'A', 2, stm32f1xx_hal::gpio::Input<PullUp>>,
        Delay<stm32f1xx_hal::pac::TIM3, ADS1256_TIMER_CLOCK_FREQ>,
    >;

    #[shared]
    struct Shared {
        ads1256: Ads1256,
    }

    #[local]
    struct Local {
        hc05_tx: stm32f1xx_hal::serial::Tx1,
        hc05_rx: stm32f1xx_hal::serial::Rx1,
        send_timer: Counter<stm32f1xx_hal::pac::TIM1, SEND_TIMER_CLOCK_FREQ>,
        read_timer: Counter<stm32f1xx_hal::pac::TIM2, READ_TIMER_CLOCK_FREQ>,
        dymh_106_data_producer: Producer<'static, TensionData, DYMH_106_QUEUE_SIZE>,
        dymh_106_data_consumer: Consumer<'static, TensionData, DYMH_106_QUEUE_SIZE>,
    }

    #[init(local = [dymh106_queue: Queue<TensionData, DYMH_106_QUEUE_SIZE> = Queue::new()])]
    fn init(cx: init::Context) -> (Shared, Local) {
        defmt::info!("init");

        // Take ownership over the raw flash and rcc devices and convert them into the corresponding
        // HAL structs
        let mut flash: stm32f1xx_hal::flash::Parts = cx.device.FLASH.constrain();
        let rcc: stm32f1xx_hal::rcc::Rcc = cx.device.RCC.constrain();

        // Freeze the configuration of all the clocks in the system and store the frozen frequencies in
        // `clocks`
        // with those values one second equals 'delay_cycles: u32 = 72_000_000'
        let clocks = rcc
            .cfgr
            .use_hse(8.MHz())
            .sysclk(MAIN_CLOCK_FREQ.Hz())
            .pclk1(36.MHz())
            .pclk2(MAIN_CLOCK_FREQ.Hz())
            .freeze(&mut flash.acr);

        if !clocks.usbclk_valid() {
            panic!("Clock parameter values are wrong!");
        }

        let mut gpioa = cx.device.GPIOA.split();
        let mut afio = cx.device.AFIO.constrain();

        // Configure the ads1256  driver:
        //
        // SPI pins:
        // MOSI  - PA7 // DIN
        // MISO  - PA6 // DOUT
        // SCK	 - PA5 // SCLK
        // SS	 - PA4 // CS
        // --------------------
        // --------------------
        // Other pins:
        // DRDY  - PA2
        // PDWN  - +3.3 V
        let spi_pins = (
            gpioa.pa5.into_alternate_push_pull(&mut gpioa.crl),
            gpioa.pa6,
            gpioa.pa7.into_alternate_push_pull(&mut gpioa.crl),
        );
        let ads1256_spi = spi::Spi::spi1(
            cx.device.SPI1,
            spi_pins,
            &mut afio.mapr,
            embedded_hal::spi::MODE_1,
            1920000.Hz(),
            clocks,
        );
        let cs_pin = gpioa.pa4.into_push_pull_output(&mut gpioa.crl);
        // reset_pin does not used anywhere in ADS1256 codebase
        let reset_pin = gpioa.pa3.into_push_pull_output(&mut gpioa.crl);
        let data_ready_pin = gpioa.pa2.into_pull_up_input(&mut gpioa.crl);
        let timer = stm32f1xx_hal::timer::FTimer::<stm32f1xx_hal::pac::TIM3, ADS1256_TIMER_CLOCK_FREQ>::new(cx.device.TIM3, &clocks);
        let mut ads1256 = ADS1256::new(ads1256_spi, cs_pin, reset_pin, data_ready_pin, timer.delay()).unwrap();

        let config = Ads1256Config::new(SamplingRate::Sps7500, PGA::Gain64);
        ads1256.set_config(&config).unwrap();

        // Configure the USART1:
        // USART1 for HC-05
        // hc-05 RX - PA9
        // hc-05 TX - PA10
        let hc05_tx = gpioa.pa9.into_alternate_push_pull(&mut gpioa.crh);
        let hc05_rx = gpioa.pa10.into_pull_up_input(&mut gpioa.crh);
        // 115200 -> 115200 bits/s
        // 230400 -> 230400 bits/s
        // 460800 -> 460800 bits/s
        // 921600 -> 921600 bits/s
        // 1382400 -> 1382400 bits/s
        let mut serial_usart1 = Serial::new(
            cx.device.USART1,
            (hc05_tx, hc05_rx),
            &mut afio.mapr,
            Config::default()
                .baudrate(460800.bps())
                .wordlength_8bits()
                .stopbits(stm32f1xx_hal::serial::StopBits::STOP1)
                .parity_none(),
            &clocks,
        );
        serial_usart1.listen(stm32f1xx_hal::serial::Event::Rxne);
        let (hc05_tx, hc05_rx) = serial_usart1.split();

        // Timer to read from ADS1256
        let mut read_timer = robot_core::get_counter(cx.device.TIM2, &clocks);
        read_timer.start(DYMH_106_REQ_FREQ.Hz::<1, 1>().into_duration()).unwrap();
        read_timer.listen(Event::Update);
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

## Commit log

2023-06-27 add stepper bin - works with 17HS15-1704S
2023-06-27 stepper works with enable_motion_control
2023-07-03 add comment to TIMER_CLOCK_FREQ value
2023-07-09 learn how to work with timers
2023-07-09 for some reason 'steps_by_timer' moves faster then 'manual_steps'; motor doesnt work if delay is < 1_000_000 nanos in 'manual_steps', but works with 800_000 in 'steps_by_timers'
2023-07-09 add new example - stepper with potentiometr
2023-07-10 moved to skr e3-dip and add control 4 steppers
2023-07-11 move stepper logic to Struct
2023-07-16 bluetooth works with interrupts
2023-07-18 add thread on a coil speed calculation
2023-07-22 two bluetooth devices works on SKR E3
2023-07-22 can control stepper with PS3 controller
2023-07-29 add error logging when sending command to stepper_1
    [main.rs]
2023-08-08 parsing data from esp32 (ps3 controller bluetooth module)
2023-08-08 increase channel capacity to 2
2023-08-09 control stepper1 by ps3 left sticker
2023-08-15 moved steppers creation into separate file
2023-08-15 move 4 steppers simultaneously
2023-08-15 can control each stepper separetely
2023-08-15 can control each stepper separetely and steps count
2023-08-15 add L1 L2 R1 R2 buttons on PS3
2023-08-18 increase ps3 channel capacity to 32
2023-08-27 steppers sending text to oled
2023-08-27 add open scad files
    [katushka_scad.scad, platform.scad]
2023-08-29 add open scad platform file
    [platform.scad]
2023-09-03 add gearbox scad file
    [Nema17.stl, gears.scad, planetary_gearbox.scad]
2023-09-03 change axel to my custom one
    [planetary_gearbox.scad]
2023-09-06 add library from https://github.com/solidboredom/constructive/
    [constructive-compiled.scad]
2023-09-06 remove unused holes
    [planetary_gearbox.scad]
2023-10-03 add stl files
    [gearbox_carrier_bottom.stl, gearbox_carrier_top.stl, gearbox_fixer.stl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]
2023-10-15 can control TMC2209 via UART
2024-05-13 remove 'stepper' lib usage
2024-05-14 works, but unstable for some reason
    [software_serial_read_stepper.rs]
2024-05-14 works stable with high freq timer
2024-05-15 add SoftwareSerial implementation in the similar fashion as in Arduino
2024-05-17 add README about esp32 arduino
2024-05-19 moved SoftwareSerial Arduino logic struct to 'second_try.rs' and change bin/software_serial_read_stepper.rs to be simplier
2024-05-21 working on configurator for stepper driver
2024-05-21 still working on configurator for stepper driver
2024-05-22 find why not works, but not the reason
    [software_serial_read_stepper.rs]
2024-05-27 working on tmc2209 communicator timer - trying to find some magic
2024-05-27 find MIN & MAX delays for tmc2209 timer
2024-05-29 add hx711 non-spi example
2024-06-01 remote 'flip-link' linker for Companion object, which suppose to work on BluePill
    [main.rs]
2024-06-07 add hc-05 arduino configurator
2024-06-13 add ads1256 documentation, cause hx711 is too slow (80HZ max)
2024-06-14 connected successfully, but data is in wrong format
    [ads1256_read.rs]
2024-06-19 add PCB for companion
    [companion_pcb.kicad_pcb, companion_pcb.kicad_sch]
2024-06-21 working on 'motherboard' to work with 4 steppers simultaneously
2024-06-21 working on use 4 tmc2209 steppers and trying to avoid copypasting code
    [change_speed_based_on_tensor_data.rs, lib.rs, main.rs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]
2024-06-23 add manual pin state chaning and it works
2024-06-23 add trait ManualPin to manually control pin mode without have '&mut cr'
2024-08-02 add manual steppers control from ps3
2024-08-27 optimize free mode speed sending(commands to driver)

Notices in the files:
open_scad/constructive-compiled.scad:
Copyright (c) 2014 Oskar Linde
